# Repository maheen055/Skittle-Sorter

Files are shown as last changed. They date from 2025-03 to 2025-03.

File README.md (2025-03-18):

# Skittle-Sorter

Welcome to my Skittle Sorter, a project I created back in high school with the goal of making candy-sorting more accessible for colorblind individuals. Inspired by various community projects (including one from Hackaday), this device uses an Arduino Nano, a TCS34725 RGB sensor, and two servo motors to automatically detect and sort Skittles by color.

# Colorblind Accessibility
The project helps people who are colorblind quickly separate Skittles. By automating the color-detection step, everyone can easily enjoy color-coded candy without guesswork.

# High School Roots
Built as part of my high school engineering course, this project taught me practical electronics, coding, and mechanical design. I hope it inspires other students and hobbyists to experiment with robotics and accessibility-oriented solutions.

# How It Works
1. Load Skittles
Drop Skittles into the top reservoir.

2. Color Detection
A TCS34725 sensor reads the candy color; an RGB LED lights up to indicate the detected hue.

3. Servo Sorting
Two servo motors rotate test tubes into position, releasing each Skittle into the correct slot based on the sensor reading.

4. Accessible Design
Because color recognition is fully automated, this design removes the need to visually distinguish subtle color differences—helpful for those with visual impairments.

# Hardware & Assembly
1. Microcontroller: Arduino Nano (or compatible board)
2. Color Sensor: TCS34725
3. Servo Motors: 2× MG90S
4. LED: Common-cathode RGB LED
5. Power: 9–12V supply + buck converter for stable 5V output
6. 3D-Printed Parts: Main enclosure, gears, brackets
7. Misc.: Screws, wires, test tubes, etc.

# Customization
1. Color Thresholds
Adjust the TCS34725 detection limits in the Arduino code to better match your Skittles batch or ambient lighting conditions.

2. Servo Angles
Fine-tune angles for faster or smoother sorting in the code’s variables.

3. LED Feedback
Adapt the LED color values to highlight unique palettes or to flash patterns when detecting each color.

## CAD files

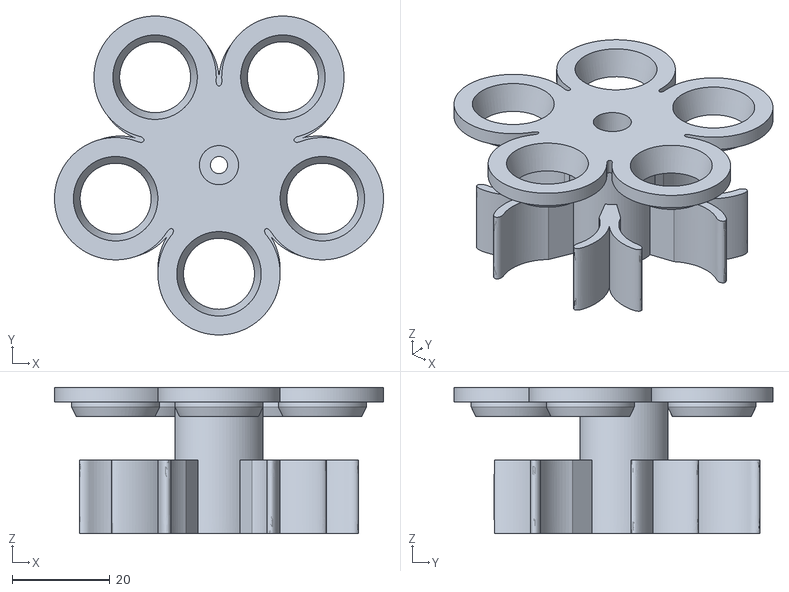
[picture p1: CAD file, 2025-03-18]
holder.stl
67.3 x 65.2 x 29.9

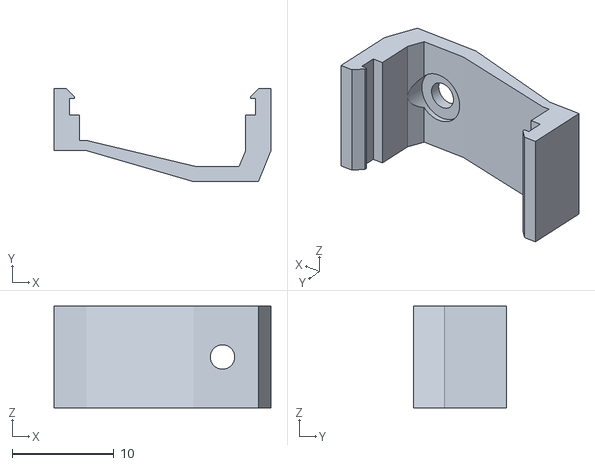
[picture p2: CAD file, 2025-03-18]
arduino_bracket.stl
21.3 x 9.13 x 10.0

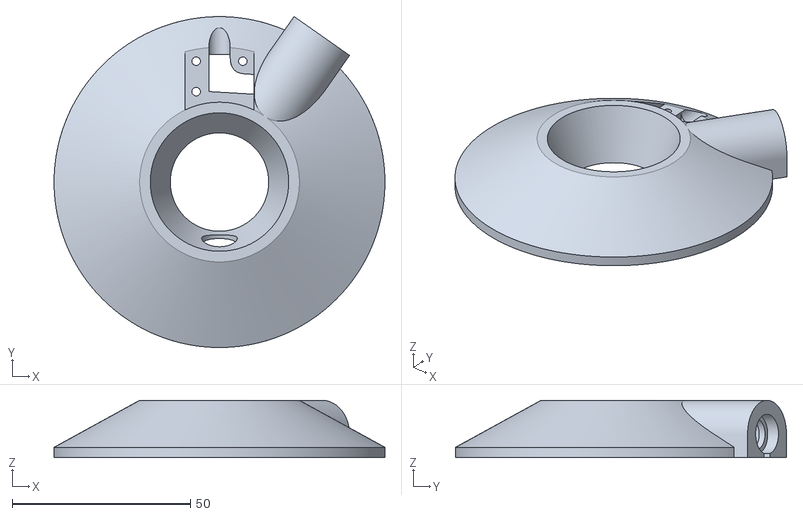
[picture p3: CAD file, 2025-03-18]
base.stl
92.9 x 92.9 x 16.1

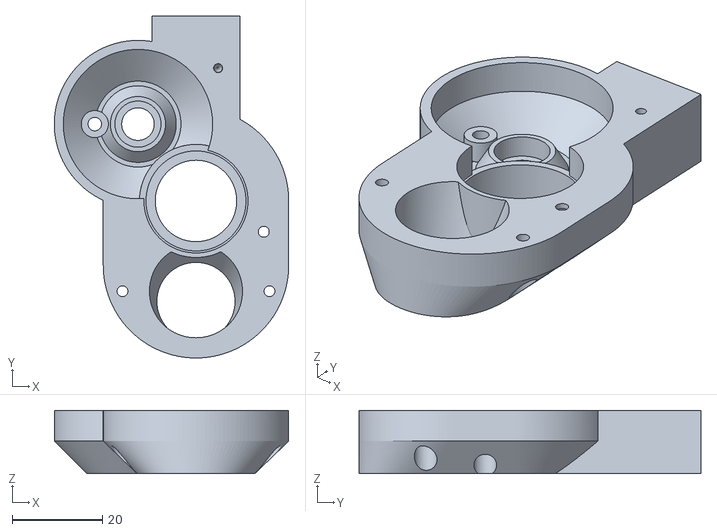
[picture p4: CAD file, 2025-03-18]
carrier.stl
51.8 x 75.6 x 14.0

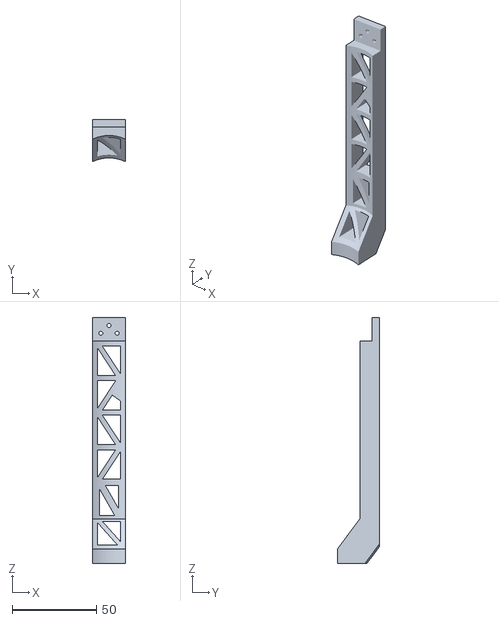
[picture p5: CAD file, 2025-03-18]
leg.stl
19.4 x 25.2 x 145.8

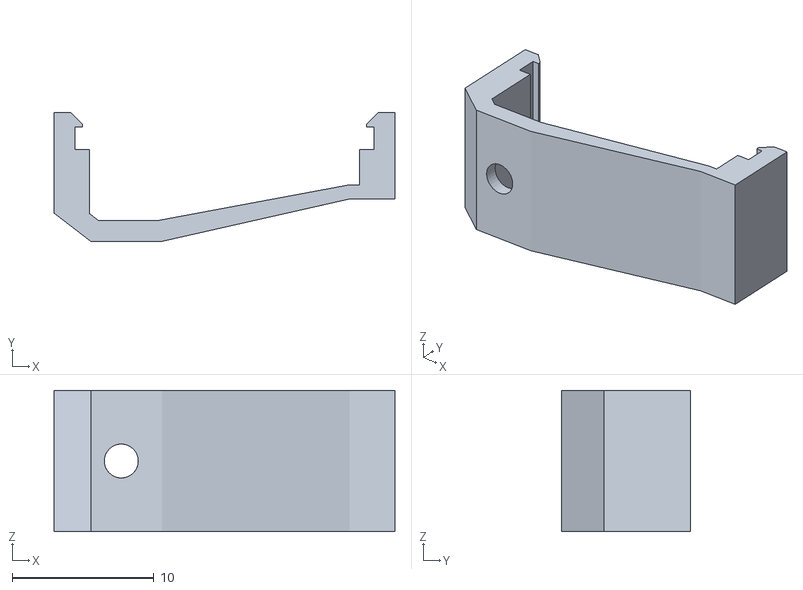
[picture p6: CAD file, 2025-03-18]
regulator_bracket.stl
24.1 x 9.10 x 10.0

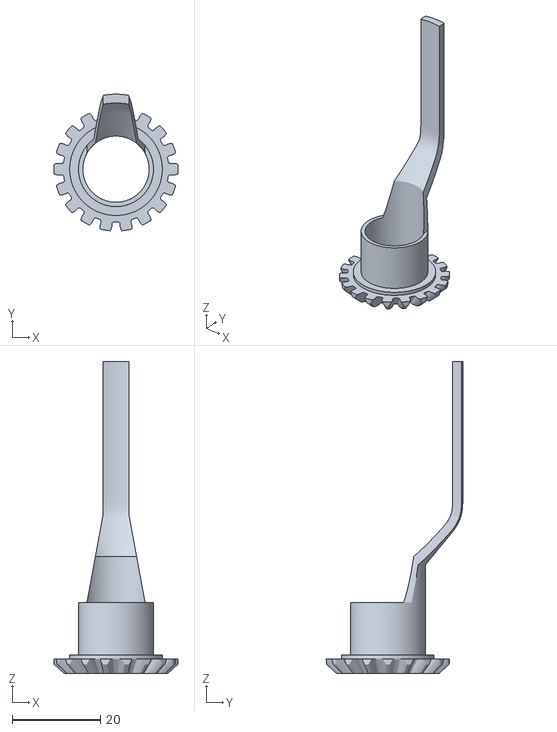
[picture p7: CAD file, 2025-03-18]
top_gear.stl
28.1 x 31.0 x 70.7

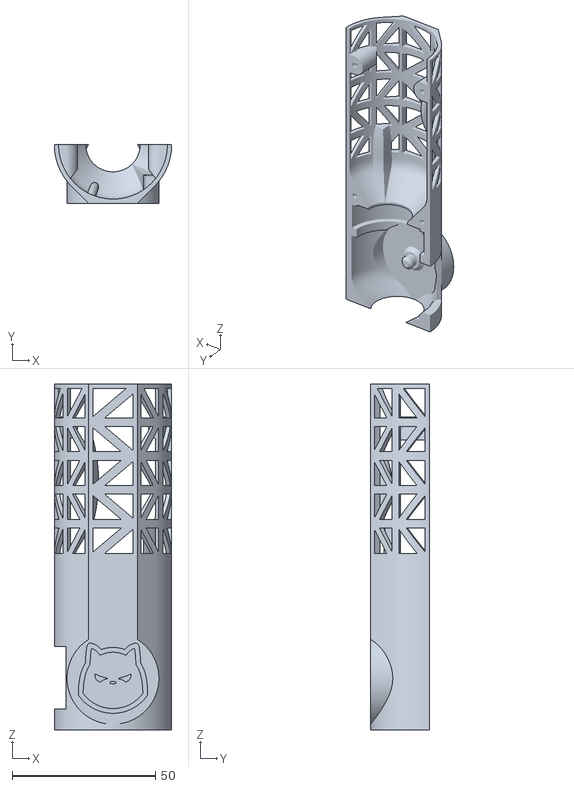
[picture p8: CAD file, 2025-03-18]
front_shell_mesh.stl
41.0 x 20.5 x 120.9

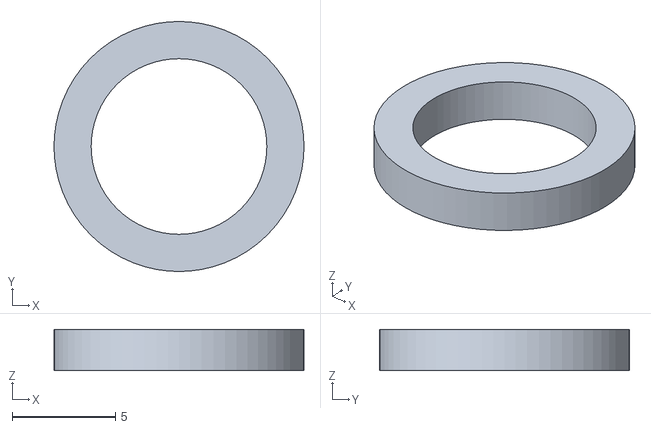
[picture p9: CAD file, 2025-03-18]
spacer.stl
12.1 x 12.1 x 2.00

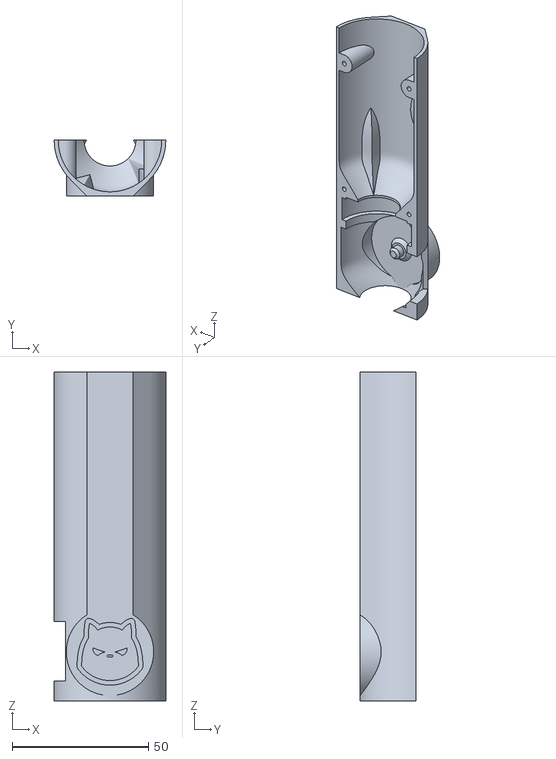
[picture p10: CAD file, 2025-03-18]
front_shell_solid.stl
41.0 x 20.5 x 120.9

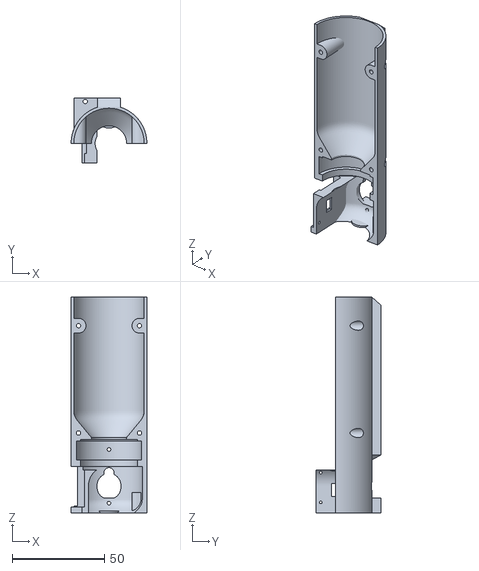
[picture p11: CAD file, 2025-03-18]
rear_shell.stl
41.0 x 34.9 x 116.8

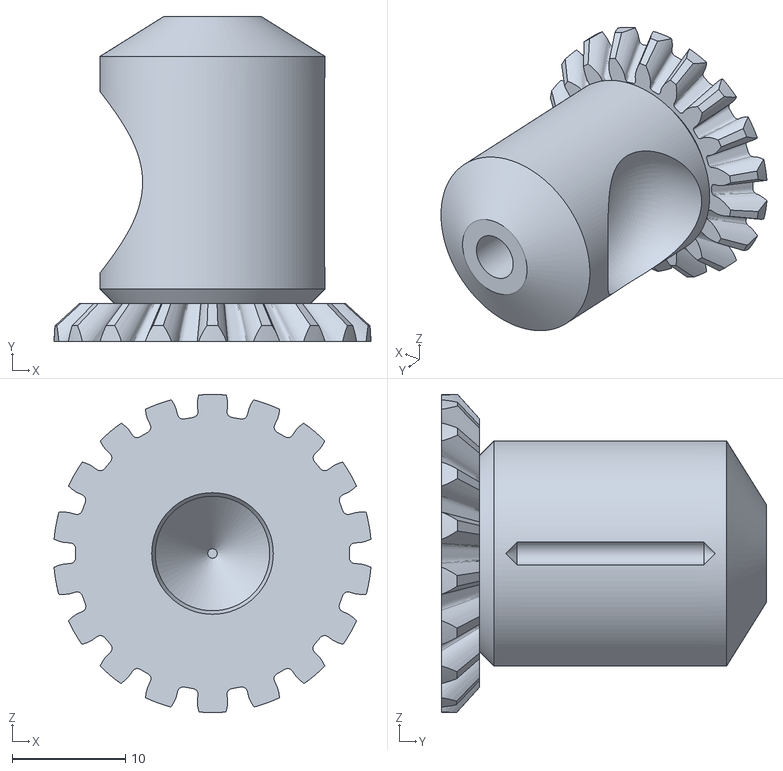
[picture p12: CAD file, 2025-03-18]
servo_gear.stl
28.0 x 28.7 x 28.1

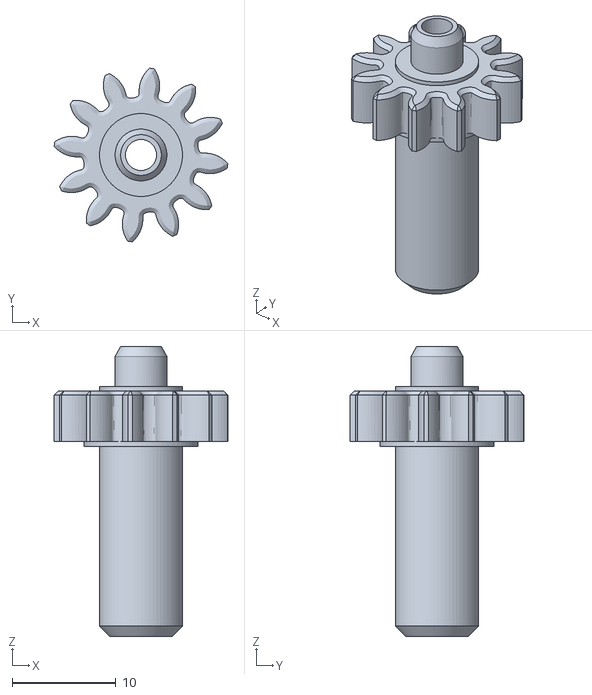
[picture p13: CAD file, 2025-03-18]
small_gear.stl
16.8 x 16.8 x 28.0

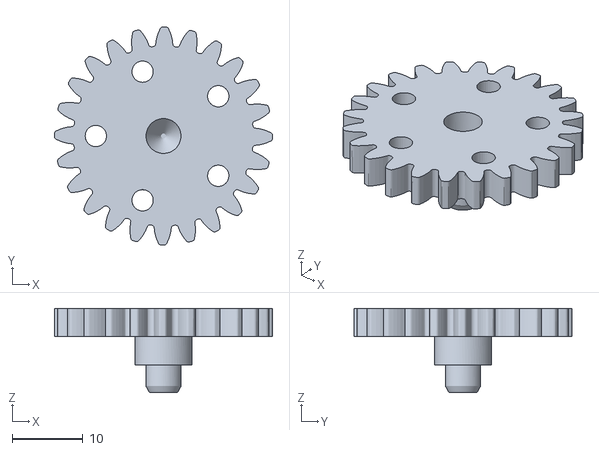
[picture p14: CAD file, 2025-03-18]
big_gear.stl
30.7 x 30.7 x 11.9

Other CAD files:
gear_cap.stl

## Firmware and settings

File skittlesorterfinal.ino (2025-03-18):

/*
*Skittle Sorter
*This sketch uses an Arduino board and the circuit shown in the diagram above
*to sort skittles by color. The RGB sensor is used to detect the color of each skittle,
*and the servos are used to sort the skittles into designated test tubes.
*Author: Maheen Shoaib
*Date: January 25, 2023
*/

#include <Wire.h> // library for communication with I2C devices
#include "Adafruit_TCS34725.h" // library for the RGB sensor
#include<Servo.h> // library for controlling servo motors

/* Based on example code for the Adafruit TCS34725 breakout library */


//=======================Variables related to RGB sensor=========================


Adafruit_TCS34725 tcs = Adafruit_TCS34725(TCS34725_INTEGRATIONTIME_24MS, TCS34725_GAIN_1X);  // setup RGB sensor

int colour = 0;//0-black, 1-yelow, 2-green, 3-orange, 4-red, 5-purple
int previous_colour = colour;
int black_count = 0;  // count of empty/unknown color

int start_measurment_angle = 88; //servo position to align skittle in front of sensor
int measurment_sweep = 2; //number of measure taken . used to average error
int measurment_angle_increment = 4; //angle increment between measurments

//limit values[] = {min_red_values, max_red_values, min_green_values, max_green_values, min_blue_values, max_blue_values}
uint16_t black_limit_values[] = {0, 200, 0, 200, 0, 200};// color limit values for blank (no skittle)
uint16_t yellow_limit_values[] = {850, 2200, 800, 2200, 400, 1100};// color limit values for yellow
uint16_t green_limit_values[] = {350, 800, 650, 1400, 250, 700};// color limit values for green
uint16_t orange_limit_values[] = {650, 1800, 300, 850, 210, 600};// color limit values for orange
uint16_t red_limit_values[] = {400, 950, 150, 450, 150, 400};// color limit values for red
uint16_t purple_limit_values[] = {150, 400, 150, 450, 150, 500};// color limit values for purple

//=======================Variables related to RGB led=========================

// pin for the red element of the RGB LED
byte R_pin = 5;
// pin for the green element of the RGB LED
byte G_pin = 6;
// pin for the blue element of the RGB LED
byte B_pin = 11;
// variable to store the current intensity of the red element of the RGB LED
int current_red_value = 255;
// variable to store the current intensity of the green element of the RGB LED
int current_green_value = 255;
// variable to store the current intensity of the blue element of the RGB LED
int current_blue_value = 255;

// array to store the intensity values for the orange color
int orange[] = {255, 30, 0};
// array to store the intensity values for the red color
int red[] = {255, 0, 0};
// array to store the intensity values for the green color
int green[] = {0, 204, 0};
// array to store the intensity values for the yellow color
int yellow[] = {255, 255, 0};
// array to store the intensity values for the purple color
int purple[] = {102, 0, 204};

//======================= Variables related to feeder servos =========================

// delay before releasing the skittle into the test tube
int release_delay = 220;
// angles of the test tubes
int colour_angles[] = {20, 59, 95, 135, 173};
// constant value used to adjust for backlash when moving the feeder servo in the backward direction
const int backward_anti_backlash = 2;
// constant value used to adjust for backlash when moving the feeder servo in the forward direction
const int forward_anti_backlash = 2;
Servo feeder_servo; //declare feeder servo
Servo holder_servo; //declare tubes holder servo

//=================================== SETUP =========================================

void setup(void) {
  
  Serial.begin(9600); // Start serial communication at 9600 baud rate

  pinMode(R_pin, OUTPUT);   // Set the pin mode for R_pin as OUTPUT 
  pinMode(G_pin, OUTPUT);   // Set the pin mode for G_pin as OUTPUT 
  pinMode(B_pin, OUTPUT);   // Set the pin mode for B_pin as OUTPUT 

  analogWrite(R_pin, 255);  // Turn off the red element of the RGB LED by setting its value to 255
  analogWrite(G_pin, 255);  // Turn off the green element of the RGB LED by setting its value to 255
  analogWrite(B_pin, 255);  // Turn off the blue element of the RGB LED by setting its value to 255

  feeder_servo.attach(3);  // Attach the feeder servo to pin 3
  holder_servo.attach(2);   // Attach the holder servo to pin 2
  feeder_servo.write(0);    // Initial position of the feeder servo is set to 0
  holder_servo.write(colour_angles[0]); // Initial position of the holder servo is set to the first angel in the colour_angles array

  int white[] = {0, 0, 0}; //local white values variable
  int black[] = {255, 255, 255}; //local black values variable
  set_led(1000, white);   // turn LED on (white)

  if (tcs.begin()) {    //check if sensor found
    Serial.println("Found sensor");
    starting_sequence();
  } else {
    Serial.println("No TCS34725 found ... check your connections");
    while (1)  //fast red blinking if sensor not found
    {
      set_led(300, red);
      set_led(300, black);
    }
  }
}

//=================================== LOOP =========================================

void loop(void) {

  if (black_count < 10) // Check if the black_count is less than 10
  {
    feeder_servo.write(0); // Set the servo position to the top for skittle collection
    delay(450);  // Delay to let the feeder servo enough time to get in position
    previous_colour = colour;
    get_colour(); // Read skittle colour

    if (colour == 0) {
      black_count ++; //If no colour found, increment black count
      shake();// Gives a bit more shake to the reservoir even if no skittle is there
    }
    else if (colour == 6) {
      black_count ++; // If colour unknown, increment black count - no skittle release
    }
    else { // If colour found
      move_holder(); // Move tube holder
      release_skittle(); // Release skittle
      black_count = 0;
    }
  }

  else { // If black_count is greater than or equal to 10
    end_loop(1000); // End the loop and wait for 1 second
  }
}

//=================================== GET COLOUR =========================================

void get_colour() {

  uint16_t r, g, b, c;//, colorTemp, lux;
  uint16_t total_r = 0;
  uint16_t total_g = 0;
  uint16_t total_b = 0;

  feeder_servo.write(start_measurment_angle); //move to start measurement angle
  delay(200);

  Serial.println("----------------");
  for (int i = 0; i <= measurment_sweep; i++) //loop for each measure
  {
    tcs.getRawData(&r, &g, &b, &c);    //get color data

    feeder_servo.write(start_measurment_angle + i * measurment_angle_increment); //increment servo angle for next measure
    total_r += r; //add red value to total red value
    total_g += g; //add green value to total green value
    total_b += b; //add blue value to total blue value
    delay(15);
  }


  total_r /= measurment_sweep;  //average values across all measurements
  total_g /= measurment_sweep;
  total_b /= measurment_sweep;

  Serial.print(total_r); Serial.print(" ");
  Serial.print(total_g); Serial.print(" ");
  Serial.print(total_b); Serial.print(" ");
  Serial.println(" ");

  //compare values to determine the color .
  if ((total_r < black_limit_values[1]) &&    //check for black
      (total_g < black_limit_values[3]) &&
      (total_b < black_limit_values[5]))
  { Serial.println("black");
    colour = 0;
  }
  else if ((total_r >= yellow_limit_values[0]) &&   //check for yellow
           (total_r < yellow_limit_values[1]) &&
           (total_g >= yellow_limit_values[2]) &&
           (total_g < yellow_limit_values[3]) &&
           (total_b >= yellow_limit_values[4]) &&
           (total_b < yellow_limit_values[5]))
  { Serial.println("yellow");
    colour = 1;
  }
  else if ((total_r >= green_limit_values[0]) &&   //check for green
           (total_r < green_limit_values[1]) &&
           (total_g >= green_limit_values[2]) &&
           (total_g < green_limit_values[3]) &&
           (total_b >= green_limit_values[4]) &&
           (total_b < green_limit_values[5]))
  { Serial.println("green");
    colour = 2;
  }
  else if ((total_r >= orange_limit_values[0]) &&   //check for orange
           (total_r < orange_limit_values[1]) &&
           (total_g >= orange_limit_values[2]) &&
           (total_g < orange_limit_values[3]) &&
           (total_b >= orange_limit_values[4]) &&
           (total_b < orange_limit_values[5]))
  { Serial.println("orange");
    colour = 3;
  }
  else if ((total_r >= red_limit_values[0]) &&   //check for red
           (total_r < red_limit_values[1]) &&
           (total_g >= red_limit_values[2]) &&
           (total_g < red_limit_values[3]) &&
           (total_b >= red_limit_values[4]) &&
           (total_b < red_limit_values[5]))
  { Serial.println("red");
    colour = 4;
  }
  else if ((total_r >= purple_limit_values[0]) &&   //check for purple
           (total_r < purple_limit_values[1]) &&
           (total_g >= purple_limit_values[2]) &&
           (total_g < purple_limit_values[3]) &&
           (total_b >= purple_limit_values[4]) &&
           (total_b < purple_limit_values[5]))
  { Serial.println("purple");
    colour = 5;
  }
  else {
    Serial.println("unknown");    //if color not detected, set colour to 0 to force new check
    colour = 6;
  }

}

//============================== MOVE HOLDER =============================
// adjust delay depending how much the holder needs to move
// include an backlash compensation

void move_holder() {

 int new_holder_position = colour_angles[colour - 1]; //gets new position of tube
  int holder_delay = (abs(previous_colour - colour) * 70);// - release_delay; //leaves 70ms for the holder servo to turn 36 degrees

  if (holder_delay < 0) {  //keep delay superior to 0
    holder_delay = 0;
  }
  if (previous_colour > colour)
  {
    //forces the holder servo to go back further than normal position to compensation for gearing backlash
    int anti_backlash_angle = new_holder_position - backward_anti_backlash;
    holder_servo.write(anti_backlash_angle);
    //delay(holder_delay);
  }
  else
  {
    int anti_backlash_angle = new_holder_position + forward_anti_backlash;
    //holder_servo.write(anti_backlash_angle);
    holder_servo.write(new_holder_position); // move holder in position
    //delay(holder_delay);
  }

  if (colour == 1) {
    set_led(holder_delay , yellow);
  }
  else if (colour == 2) {
    set_led(holder_delay , green);
  }
  else if (colour == 3) {
    set_led(holder_delay , orange);
  }
  else if (colour == 4) {
    set_led(holder_delay , red);
  }
  else if (colour == 5) {
    set_led(holder_delay , purple);
  }
  else {}

}

//=============================  RELEASE SKITTLE  ===========================

void release_skittle() {

  feeder_servo.write(180); // set servo position to the bottom for skittle release
  delay(release_delay);

}

//=================================  SHAKE  =================================

void shake() {
  
  int shake_delay = 80;
  int shake_amount = 5;
  int shake_min_value = 90;
  int shake_max_value = 180;

  feeder_servo.write(180); // set servo position to the bottom for skittle release
  delay(release_delay);
  feeder_servo.write(120); // set servo position to the bottom for skittle release
  delay(80);
  for (int i = 0; i <= shake_amount; i++) //loop for each measure
  {
    feeder_servo.write(shake_min_value); // set servo position to the bottom for skittle release
    delay(shake_delay);
    feeder_servo.write(shake_max_value); // set servo position to the bottom for skittle release
    delay(shake_delay);
  }
}

//============================ STARTING SEQUENCE ============================

void starting_sequence() {

  colour = 1;
  move_holder();
  set_led(300, yellow);
  delay (400);

  colour = 2;
  move_holder();
  set_led(300, green);
  delay (400);

  colour = 3;
  move_holder();
  set_led(300, orange);
  delay (400);

  colour = 4;
  move_holder();
  set_led(300, red);
  delay (400);

  colour = 5;
  move_holder();
  set_led(300, purple);
  delay (400);

  previous_colour = colour;
  colour = 3;
  move_holder();

  end_loop(200);
}

//================================ END LOOP =================================

void end_loop(int duration) {

  set_led(duration , orange);
  set_led(duration , red);
  set_led(duration , green);
  set_led(duration , yellow);
  set_led(duration , purple);
}

//============================   SET RGB LED COLOUR   =======================
//   This act as a delay() but allows the LED to change color while waiting .

void set_led(int duration, int color[3]) {

  int start_time = millis();     // start time value
  int current_time = start_time; // current time value
  int current_duration = 0;      // total duration

  while (current_duration < duration)
  {
    analogWrite(R_pin, map(current_duration, 0, duration, current_red_value, color[0]));  //ramp up red value for each loop
    analogWrite(G_pin, map(current_duration, 0, duration, current_green_value, color[1])); //ramp up green value for each loop
    analogWrite(B_pin, map(current_duration, 0, duration, current_blue_value, color[2])); //ramp up blue value for each loop

    current_time = millis();   //update current time
    current_duration = current_time - start_time;  //calculate total duration
  }

  current_red_value = color[0];   // set new red current value
  current_green_value = color[1]; // set new green current value
  current_blue_value = color[2];  // set new blue current value

}
